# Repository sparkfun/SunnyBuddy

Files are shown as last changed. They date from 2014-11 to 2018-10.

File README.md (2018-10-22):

Sunny Buddy - MPPT Solar Charger
================================

Sunny Buddy

[*Sunny Buddy (PRT-12885)*](https://www.sparkfun.com/products/12885)

This is a maximum power point tracking solar charger for single-cell LiPo batteries. 

Repository Contents
-------------------
* **/Fritzing** - Fritzing Example wiring images
* **/Hardware** - All Eagle design files (.brd, .sch)
* **/Production** - Test bed files and production panel files

Documentation
--------------
* **[Hookup Guide](https://learn.sparkfun.com/tutorials/sunny-buddy-solar-charger-v13-hookup-guide)** - Basic hookup guide for the Sunny Buddy.

Product Versions
----------------
* [PRT-12885 ](https://www.sparkfun.com/products/12885 )- Version 1.3
* [PRT-12084](https://www.sparkfun.com/products/12084) - Version 1.0

Version History
---------------
* [v10](https://github.com/sparkfun/SunnyBuddy/tree/HW_V1.0) -GitHub files for v1.0

License Information
-------------------
The hardware is released under [Creative Commons ShareAlike 4.0 International](https://creativecommons.org/licenses/by-sa/4.0/).
The code is beerware; if you see me (or any other SparkFun employee) at the local, and you've found our code helpful, please buy us a round!

Distributed as-is; no warranty is given.

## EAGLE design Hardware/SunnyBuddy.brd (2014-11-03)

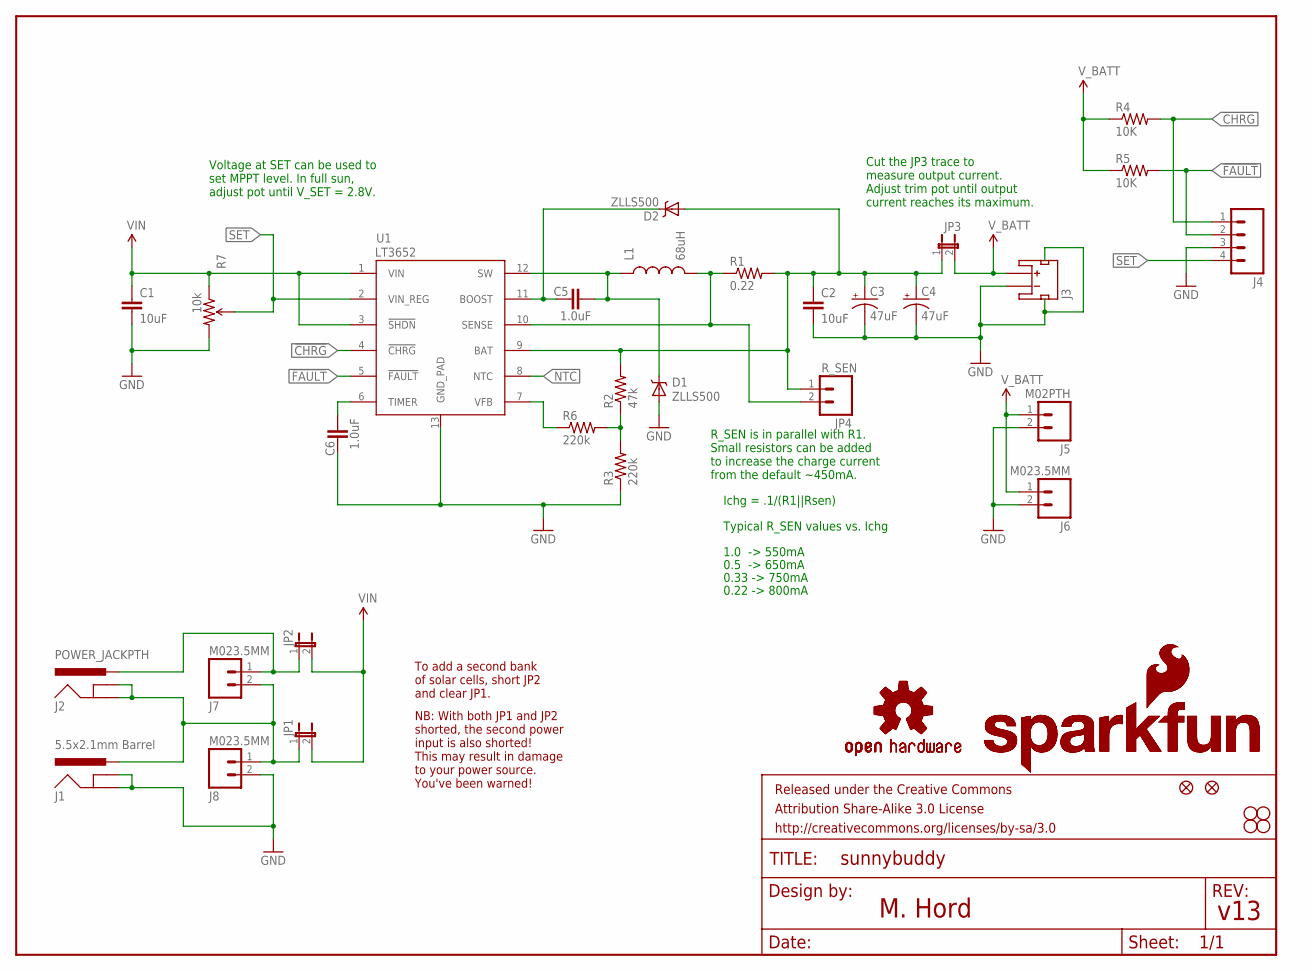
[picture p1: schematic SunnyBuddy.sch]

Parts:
C1: 10uF; 1210
C2: 10uF; 1206
C3, C4: 47uF; EIA3528
C5, C6: 1.0uF; 0603-CAP
D1, D2: ZLLS500; SOT23
FID1, FID2: FIDUCIAL1X2; FIDUCIAL-1X2
FRAME1: FRAME-LETTER; CREATIVE_COMMONS
J1: 5.5x2.1mm Barrel; POWER_JACK_SMD
J2: POWER_JACKPTH; POWER_JACK_PTH
J3: JST_2MM_MALE; JST-2-SMD
J4: M04PTH; 1X04
J5: M02PTH; 1X02
J6, J7, J8: M023.5MM; SCREWTERMINAL-3.5MM-2
JP1: JUMPER-2SMD-NC; SJ_2S
JP2: JUMPER-2SMD-NO; SJ_2S-NO
JP3: JUMPER-PTH-2-NC; PTH-JUMPER-NC_BOTTOM_NO_SILK
JP4: R_SEN; 1X02
L1: 68uH; CR75
LOGO1: SFE_LOGO_NAME_FLAME.2_INCH; SFE_LOGO_NAME_FLAME_.2
LOGO2: OSHW-LOGOM; OSHW-LOGO-M
LOGO3: OSHW-LOGOS; OSHW-LOGO-S
LOGO4: SFE_LOGO_NAME_FLAME.3_INCH; SFE_LOGO_NAME_FLAME_.3
R1: 0.22; 0805
R2: 47k; 0603-RES
R3, R6: 220k; 0603-RES
R4, R5: 10K; 0603-RES
R7: 10k; TRIMPOT-3MM
STANDOFF1, STANDOFF2, STANDOFF3, STANDOFF4: STAND-OFF
U1: LT3652; MSOP-12_GND

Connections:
!CHRG: J4.1, R4.2, U1.4 (!CHRG)
!FAULT: J4.2, R5.2, U1.5 (!FAULT)
BOOST: C5.1, D2.3 (C), U1.11 (BOOST)
FB: R2.1, R3.2, R6.2
GND: C1.2, C2.2, C3.C (-), C4.C (-), C6.1, D1.1 (A), J1.GND (GNDBREAK), J1.P$4 (GND), J3.1 (-), J3.NC1 (PAD1), J3.NC2 (PAD2), J4.3, J5.2, J6.2, J8.2, R3.1, R7.3 (CW), U1.13 (GND_PAD)
unnamed: R6.1, U1.7 (VFB)
unnamed: C2.1, C3.A (+), C4.A (+), D2.1 (A), JP3.1, JP4.1, R1.2, R2.2, U1.9 (BAT)
unnamed: J1.VIN0 (PWR), J2.GND, J2.GNDBREAK, J7.2, J8.1, JP1.1
NTC: U1.8 (NTC)
SENSE: JP4.2, L1.P$2 (2), R1.1, U1.10 (SENSE)
SET: J4.4, R7.2 (WIPER), U1.2 (VIN_REG)
SFSASDF: J2.PWR, J7.1, JP2.1
SW: C5.2, D1.3 (C), L1.P$1 (1), U1.12 (SW)
TIMER: C6.2, U1.6 (TIMER)
VIN: C1.1, JP1.2, JP2.2, R7.1 (CCW), U1.1 (VIN), U1.3 (!SHDN)
V_BATT: J3.2 (+), J5.1, J6.1, JP3.2, R4.1, R5.1

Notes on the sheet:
To add a second bank of solar cells, short JP2 and clear JP1.
NB: With both JP1 and JP2 shorted, the second power input is also shorted! This may result in damage to your power source. You've been warned!
v13
M. Hord
Cut the JP3 trace to measure output current. Adjust trim pot until output current reaches its maximum.
R_SEN is in parallel with R1. Small resistors can be added to increase the charge current from the default ~450mA.
0.22 -> 800mA
Ichg = .1/(R1||Rsen)
Typical R_SEN values vs. Ichg
1.0 -> 550mA
0.33 -> 750mA
0.5 -> 650mA
Voltage at SET can be used to set MPPT level. In full sun, adjust pot until V_SET = 2.8V.

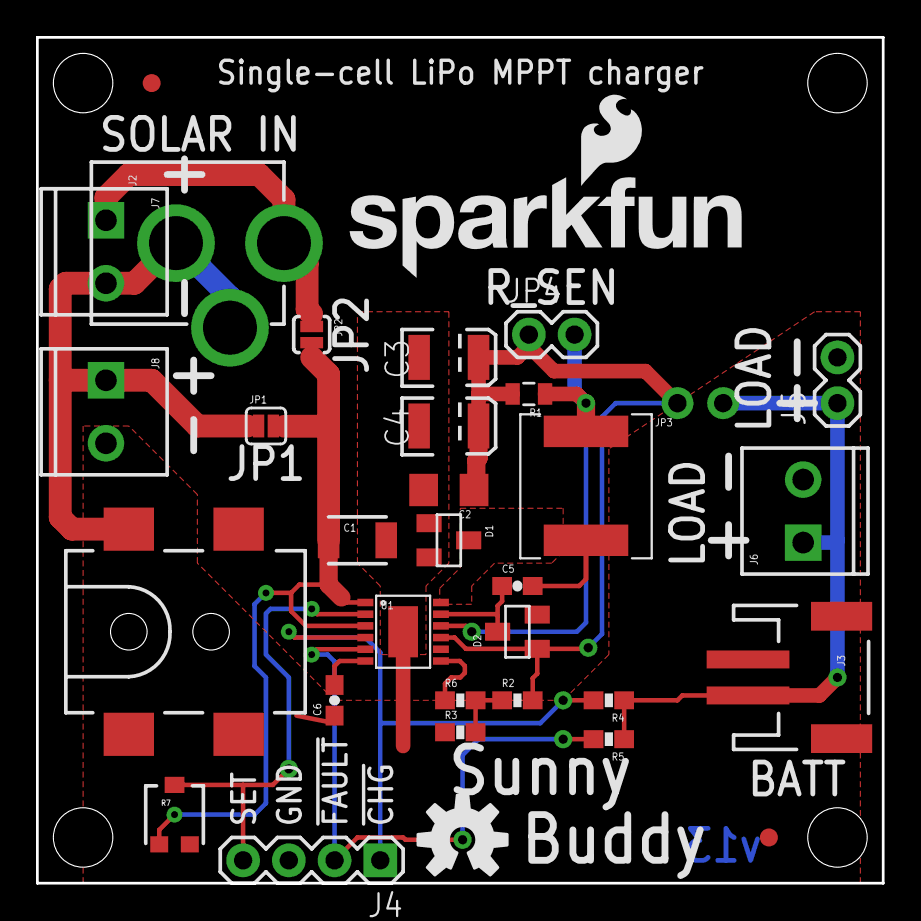
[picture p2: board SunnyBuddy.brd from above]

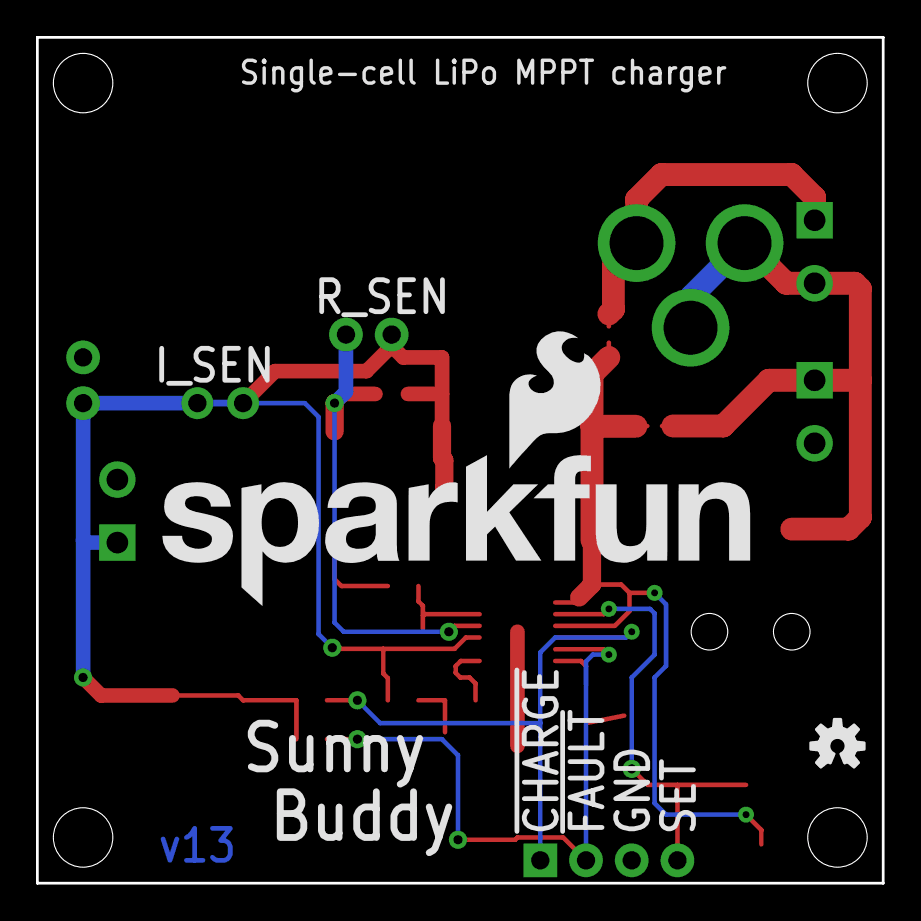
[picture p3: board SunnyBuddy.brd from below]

Board: 2 copper layers, 47.0 x 47.0 mm, 40 parts (2 on the bottom side), 15 nets.

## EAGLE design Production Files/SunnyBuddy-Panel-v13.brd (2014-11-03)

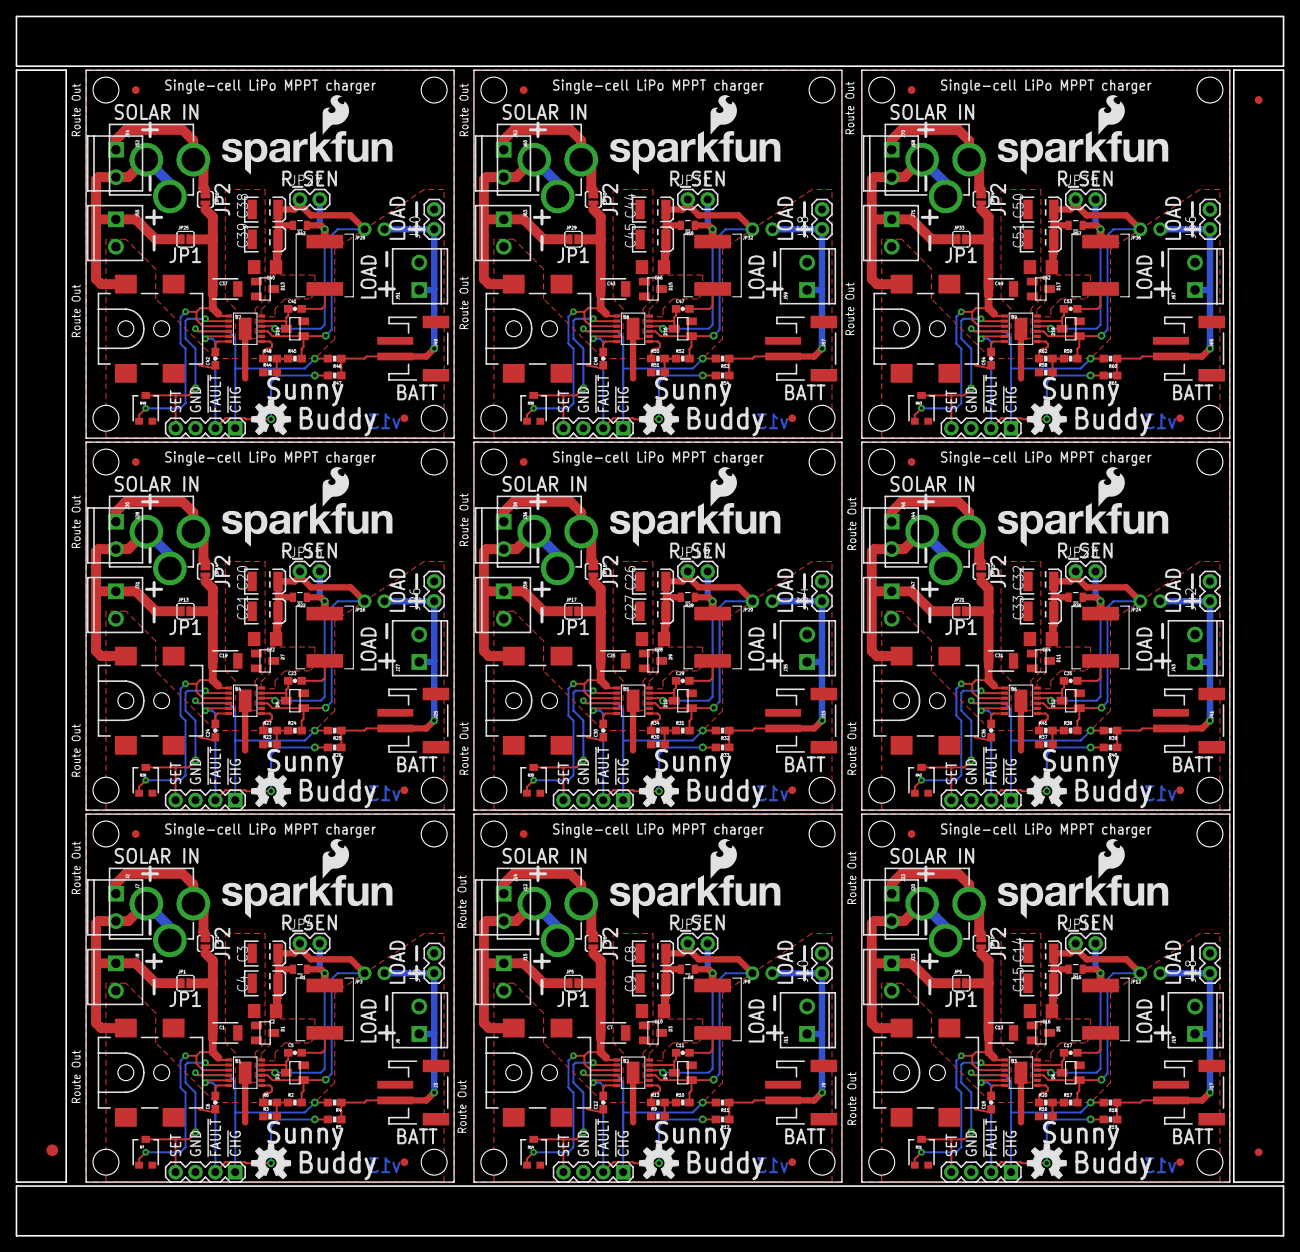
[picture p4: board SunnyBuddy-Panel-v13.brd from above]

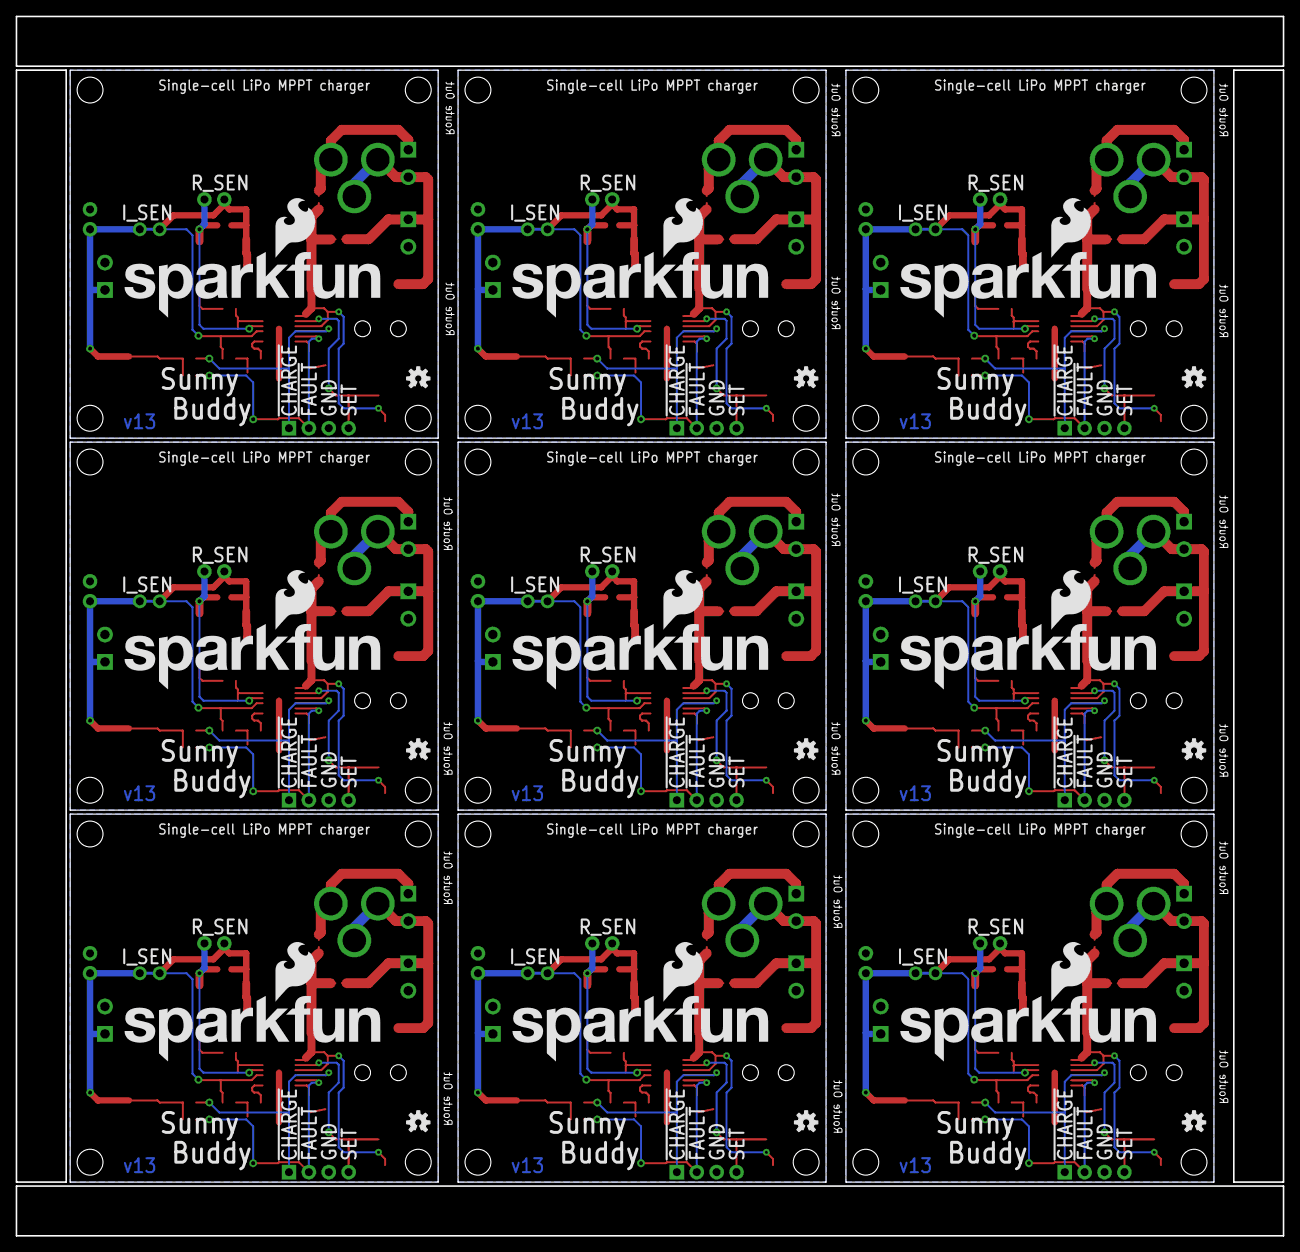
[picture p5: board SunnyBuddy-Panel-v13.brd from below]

Board: 2 copper layers, 161.8 x 155.7 mm, 354 parts (18 on the bottom side), 135 nets.

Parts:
C1, C7, C13, C19, C25, C31, C37, C43, C49: 10uF; 1210
C2, C10, C16, C22, C28, C34, C40, C46, C52: 10uF; 1206
C3, C4, C8, C9, C14, C15, C20, C21, C26, C27, C32, C33, C38, C39, C44, C45, C50, C51: 47uF; EIA3528
C5, C6, C11, C12, C17, C18, C23, C24, C29, C30, C35, C36, C41, C42, C47, C48, C53, C54: 1.0uF; 0603-CAP
D1, D2, D3, D4, D5, D6, D7, D8, D9, D10, D11, D12, D13, D14, D15, D16, D17, D18: ZLLS500; SOT23
E$1: FIDUCIAL-1.5X3
E$4, E$6: FIDUCIAL-1X2
FID1, FID2, FID3, FID4, FID5, FID6, FID7, FID8, FID9, FID10, FID11, FID12, FID13, FID14, FID15, FID16, FID17, FID18: FIDUCIAL1X2; FIDUCIAL-1X2
J1, J13, J21, J29, J37, J45, J53, J61, J69: 5.5x2.1mm Barrel; POWER_JACK_SMD
J2, J14, J22, J30, J38, J46, J54, J62, J70: POWER_JACKPTH; POWER_JACK_PTH
J3, J9, J17, J25, J33, J41, J49, J57, J65: JST-2-SMD
J4, J16, J24, J32, J40, J48, J56, J64, J72: 1X04
J5, J10, J18, J26, J34, J42, J50, J58, J66: M02PTH; 1X02
J6, J7, J8, J11, J12, J15, J19, J20, J23, J27, J28, J31, J35, J36, J39, J43, J44, J47, J51, J52, J55, J59, J60, J63, J67, J68, J71: M023.5MM; SCREWTERMINAL-3.5MM-2
JP1, JP5, JP9, JP13, JP17, JP21, JP25, JP29, JP33: SJ_2S
JP2, JP6, JP10, JP14, JP18, JP22, JP26, JP30, JP34: SJ_2S-NO
JP3, JP8, JP12, JP16, JP20, JP24, JP28, JP32, JP36: JUMPER-PTH-2-NC; PTH-JUMPER-NC_BOTTOM_NO_SILK
JP4, JP7, JP11, JP15, JP19, JP23, JP27, JP31, JP35: R_SEN; 1X02
L1, L2, L3, L4, L5, L6, L7, L8, L9: 68uH; CR75
LOGO1, LOGO5, LOGO9, LOGO13, LOGO17, LOGO21, LOGO25, LOGO29, LOGO33: SFE_LOGO_NAME_FLAME.2_INCH; SFE_LOGO_NAME_FLAME_.2
LOGO2, LOGO6, LOGO10, LOGO14, LOGO18, LOGO22, LOGO26, LOGO30, LOGO34: OSHW-LOGOM; OSHW-LOGO-M
LOGO3, LOGO7, LOGO11, LOGO15, LOGO19, LOGO23, LOGO27, LOGO31, LOGO35: OSHW-LOGOS; OSHW-LOGO-S
LOGO4, LOGO8, LOGO12, LOGO16, LOGO20, LOGO24, LOGO28, LOGO32, LOGO36: SFE_LOGO_NAME_FLAME.3_INCH; SFE_LOGO_NAME_FLAME_.3
R1, R8, R15, R22, R29, R36, R43, R50, R57: 0.22; 0805
R2, R10, R17, R24, R31, R38, R45, R52, R59: 47k; 0603-RES
R3, R6, R9, R13, R16, R20, R23, R27, R30, R34, R37, R41, R44, R48, R51, R55, R58, R62: 220k; 0603-RES
R4, R5, R11, R12, R18, R19, R25, R26, R32, R33, R39, R40, R46, R47, R53, R54, R60, R61: 10K; 0603-RES
R7, R14, R21, R28, R35, R42, R49, R56, R63: 10k; TRIMPOT-3MM
STANDOFF1, STANDOFF2, STANDOFF3, STANDOFF4, STANDOFF5, STANDOFF6, STANDOFF7, STANDOFF8, STANDOFF9, STANDOFF10, STANDOFF11, STANDOFF12, STANDOFF13, STANDOFF14, STANDOFF15, STANDOFF16, STANDOFF17, STANDOFF18, STANDOFF19, STANDOFF20, STANDOFF21, STANDOFF22, STANDOFF23, STANDOFF24, STANDOFF25, STANDOFF26, STANDOFF27, STANDOFF28, STANDOFF29, STANDOFF30, STANDOFF31, STANDOFF32, STANDOFF33, STANDOFF34, STANDOFF35, STANDOFF36: STAND-OFF
U1, U2, U3, U4, U5, U6, U7, U8, U9: LT3652; MSOP-12_GND

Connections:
!CHRG: J4.1, R4.2, U1.4
!CHRG1: J16.1, R11.2, U2.4
!CHRG2: J24.1, R18.2, U3.4
!CHRG3: J32.1, R25.2, U4.4
!CHRG4: J40.1, R32.2, U5.4
!CHRG5: J48.1, R39.2, U6.4
!CHRG6: J56.1, R46.2, U7.4
!CHRG7: J64.1, R53.2, U8.4
!CHRG8: J72.1, R60.2, U9.4
!FAULT: J4.2, R5.2, U1.5
!FAULT1: J16.2, R12.2, U2.5
!FAULT2: J24.2, R19.2, U3.5
!FAULT3: J32.2, R26.2, U4.5
!FAULT4: J40.2, R33.2, U5.5
!FAULT5: J48.2, R40.2, U6.5
!FAULT6: J56.2, R47.2, U7.5
!FAULT7: J64.2, R54.2, U8.5
!FAULT8: J72.2, R61.2, U9.5
BOOST: C5.1, D2.3, U1.11
BOOST1: C11.1, D4.3, U2.11
BOOST2: C17.1, D6.3, U3.11
BOOST3: C23.1, D8.3, U4.11
BOOST4: C29.1, D10.3, U5.11
BOOST5: C35.1, D12.3, U6.11
BOOST6: C41.1, D14.3, U7.11
BOOST7: C47.1, D16.3, U8.11
BOOST8: C53.1, D18.3, U9.11
FB: R2.1, R3.2, R6.2
FB1: R9.2, R10.1, R13.2
FB2: R16.2, R17.1, R20.2
FB3: R23.2, R24.1, R27.2
FB4: R30.2, R31.1, R34.2
FB5: R37.2, R38.1, R41.2
FB6: R44.2, R45.1, R48.2
FB7: R51.2, R52.1, R55.2
FB8: R58.2, R59.1, R62.2
GND: C1.2, C2.2, C3.C, C4.C, C6.1, D1.1, J1.GND, J1.P$4, J3.1, J3.NC1, J3.NC2, J4.3, J5.2, J6.2, J8.2, R3.1, R7.3, U1.13
GND1: C7.2, C8.C, C9.C, C10.2, C12.1, D3.1, J9.1, J9.NC1, J9.NC2, J10.2, J11.2, J13.GND, J13.P$4, J15.2, J16.3, R9.1, R14.3, U2.13
GND2: C13.2, C14.C, C15.C, C16.2, C18.1, D5.1, J17.1, J17.NC1, J17.NC2, J18.2, J19.2, J21.GND, J21.P$4, J23.2, J24.3, R16.1, R21.3, U3.13
GND3: C19.2, C20.C, C21.C, C22.2, C24.1, D7.1, J25.1, J25.NC1, J25.NC2, J26.2, J27.2, J29.GND, J29.P$4, J31.2, J32.3, R23.1, R28.3, U4.13
GND4: C25.2, C26.C, C27.C, C28.2, C30.1, D9.1, J33.1, J33.NC1, J33.NC2, J34.2, J35.2, J37.GND, J37.P$4, J39.2, J40.3, R30.1, R35.3, U5.13
GND5: C31.2, C32.C, C33.C, C34.2, C36.1, D11.1, J41.1, J41.NC1, J41.NC2, J42.2, J43.2, J45.GND, J45.P$4, J47.2, J48.3, R37.1, R42.3, U6.13
GND6: C37.2, C38.C, C39.C, C40.2, C42.1, D13.1, J49.1, J49.NC1, J49.NC2, J50.2, J51.2, J53.GND, J53.P$4, J55.2, J56.3, R44.1, R49.3, U7.13
GND7: C43.2, C44.C, C45.C, C46.2, C48.1, D15.1, J57.1, J57.NC1, J57.NC2, J58.2, J59.2, J61.GND, J61.P$4, J63.2, J64.3, R51.1, R56.3, U8.13
GND8: C49.2, C50.C, C51.C, C52.2, C54.1, D17.1, J65.1, J65.NC1, J65.NC2, J66.2, J67.2, J69.GND, J69.P$4, J71.2, J72.3, R58.1, R63.3, U9.13
unnamed: R6.1, U1.7
unnamed: C2.1, C3.A, C4.A, D2.1, JP3.1, JP4.1, R1.2, R2.2, U1.9
unnamed: J12.2, J13.VIN0, J14.GND, J14.GNDBREAK, J15.1, JP5.1
unnamed: J1.VIN0, J2.GND, J2.GNDBREAK, J7.2, J8.1, JP1.1
unnamed: R13.1, U2.7
unnamed: C8.A, C9.A, C10.1, D4.1, JP7.1, JP8.1, R8.2, R10.2, U2.9
unnamed: J20.2, J21.VIN0, J22.GND, J22.GNDBREAK, J23.1, JP9.1
unnamed: R20.1, U3.7
unnamed: C14.A, C15.A, C16.1, D6.1, JP11.1, JP12.1, R15.2, R17.2, U3.9
unnamed: J28.2, J29.VIN0, J30.GND, J30.GNDBREAK, J31.1, JP13.1
unnamed: R27.1, U4.7
unnamed: C20.A, C21.A, C22.1, D8.1, JP15.1, JP16.1, R22.2, R24.2, U4.9
unnamed: J36.2, J37.VIN0, J38.GND, J38.GNDBREAK, J39.1, JP17.1
unnamed: R34.1, U5.7
unnamed: C26.A, C27.A, C28.1, D10.1, JP19.1, JP20.1, R29.2, R31.2, U5.9
unnamed: J44.2, J45.VIN0, J46.GND, J46.GNDBREAK, J47.1, JP21.1
unnamed: R41.1, U6.7
unnamed: C32.A, C33.A, C34.1, D12.1, JP23.1, JP24.1, R36.2, R38.2, U6.9
unnamed: J52.2, J53.VIN0, J54.GND, J54.GNDBREAK, J55.1, JP25.1
unnamed: R48.1, U7.7
unnamed: C38.A, C39.A, C40.1, D14.1, JP27.1, JP28.1, R43.2, R45.2, U7.9
unnamed: J60.2, J61.VIN0, J62.GND, J62.GNDBREAK, J63.1, JP29.1
unnamed: R55.1, U8.7
unnamed: C44.A, C45.A, C46.1, D16.1, JP31.1, JP32.1, R50.2, R52.2, U8.9
unnamed: J68.2, J69.VIN0, J70.GND, J70.GNDBREAK, J71.1, JP33.1
unnamed: R62.1, U9.7
unnamed: C50.A, C51.A, C52.1, D18.1, JP35.1, JP36.1, R57.2, R59.2, U9.9
SENSE: JP4.2, L1.P$2, R1.1, U1.10
SENSE1: JP7.2, L2.P$2, R8.1, U2.10
SENSE2: JP11.2, L3.P$2, R15.1, U3.10
SENSE3: JP15.2, L4.P$2, R22.1, U4.10
SENSE4: JP19.2, L5.P$2, R29.1, U5.10
SENSE5: JP23.2, L6.P$2, R36.1, U6.10
SENSE6: JP27.2, L7.P$2, R43.1, U7.10
SENSE7: JP31.2, L8.P$2, R50.1, U8.10
SENSE8: JP35.2, L9.P$2, R57.1, U9.10
SET: J4.4, R7.2, U1.2
SET1: J16.4, R14.2, U2.2
SET2: J24.4, R21.2, U3.2
SET3: J32.4, R28.2, U4.2
SET4: J40.4, R35.2, U5.2
SET5: J48.4, R42.2, U6.2
SET6: J56.4, R49.2, U7.2
SET7: J64.4, R56.2, U8.2
SET8: J72.4, R63.2, U9.2
SFSASDF: J2.PWR, J7.1, JP2.1
SFSASDF1: J12.1, J14.PWR, JP6.1
SFSASDF2: J20.1, J22.PWR, JP10.1
SFSASDF3: J28.1, J30.PWR, JP14.1
SFSASDF4: J36.1, J38.PWR, JP18.1
SFSASDF5: J44.1, J46.PWR, JP22.1
SFSASDF6: J52.1, J54.PWR, JP26.1
SFSASDF7: J60.1, J62.PWR, JP30.1
SFSASDF8: J68.1, J70.PWR, JP34.1
SW: C5.2, D1.3, L1.P$1, U1.12
SW1: C11.2, D3.3, L2.P$1, U2.12
SW2: C17.2, D5.3, L3.P$1, U3.12
SW3: C23.2, D7.3, L4.P$1, U4.12
SW4: C29.2, D9.3, L5.P$1, U5.12
SW5: C35.2, D11.3, L6.P$1, U6.12
SW6: C41.2, D13.3, L7.P$1, U7.12
SW7: C47.2, D15.3, L8.P$1, U8.12
SW8: C53.2, D17.3, L9.P$1, U9.12
TIMER: C6.2, U1.6
TIMER1: C12.2, U2.6
TIMER2: C18.2, U3.6
TIMER3: C24.2, U4.6
TIMER4: C30.2, U5.6
TIMER5: C36.2, U6.6
TIMER6: C42.2, U7.6
TIMER7: C48.2, U8.6
TIMER8: C54.2, U9.6
VIN: C1.1, JP1.2, JP2.2, R7.1, U1.1, U1.3
VIN1: C7.1, JP5.2, JP6.2, R14.1, U2.1, U2.3
VIN2: C13.1, JP9.2, JP10.2, R21.1, U3.1, U3.3
VIN3: C19.1, JP13.2, JP14.2, R28.1, U4.1, U4.3
VIN4: C25.1, JP17.2, JP18.2, R35.1, U5.1, U5.3
VIN5: C31.1, JP21.2, JP22.2, R42.1, U6.1, U6.3
VIN6: C37.1, JP25.2, JP26.2, R49.1, U7.1, U7.3
VIN7: C43.1, JP29.2, JP30.2, R56.1, U8.1, U8.3
VIN8: C49.1, JP33.2, JP34.2, R63.1, U9.1, U9.3
V_BATT: J3.2, J5.1, J6.1, JP3.2, R4.1, R5.1
V_BATT1: J9.2, J10.1, J11.1, JP8.2, R11.1, R12.1
V_BATT2: J17.2, J18.1, J19.1, JP12.2, R18.1, R19.1
V_BATT3: J25.2, J26.1, J27.1, JP16.2, R25.1, R26.1
V_BATT4: J33.2, J34.1, J35.1, JP20.2, R32.1, R33.1
V_BATT5: J41.2, J42.1, J43.1, JP24.2, R39.1, R40.1
V_BATT6: J49.2, J50.1, J51.1, JP28.2, R46.1, R47.1
V_BATT7: J57.2, J58.1, J59.1, JP32.2, R53.1, R54.1
V_BATT8: J65.2, J66.1, J67.1, JP36.2, R60.1, R61.1

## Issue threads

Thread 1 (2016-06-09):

Breakout NTC pin for cold weather charging

nseidle, 2016-06-09:
From customer discussion on [weather station tutorial](https://learn.sparkfun.com/tutorials/weather-station-wirelessly-connected-to-wunderground/discuss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).

ToniCorinne, 2016-06-13:
FoTR has been pinged regarding this in Sparkle.

Closed 2016-07-19.

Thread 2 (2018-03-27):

Fritzing Files have not been updated.

dave373, 2018-03-27:
I was trying to re-configure this board for a 12V SLA and went looking for the layouts so I know which resistor is which. On the readme file, you have the current board, but the Fritzing files haven't been updated. Could someone please do this?  Thanks.

loricrotser, 2018-08-16:
Apologies for the long reply time - I am just now getting to this!

Fritzing has been updated for v1.3. Please let us know if you need anything else!

[https://github.com/sparkfun/Fritzing_Parts/blob/master/products/12885_sfe_sunny_buddy_solar_power_v13.fzpz](https://github.com/sparkfun/Fritzing_Parts/blob/master/products/12885_sfe_sunny_buddy_solar_power_v13.fzpz)

Closed 2018-08-16.

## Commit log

2013-08-14 Proto commit
    [SunnyBuddy.brd, SunnyBuddy.sch]
2013-12-04 New inductor, better fb, add CHG and FLT
    [SunnyBuddy.brd, SunnyBuddy.sch]
2013-12-04 Change version numbers
    [SunnyBuddy.brd, SunnyBuddy.sch]
2014-01-08 Release to reds, chg v#, move 1 via, add pol silk
    [SunnyBuddy.brd, SunnyBuddy.sch]
2014-01-21 Added local board fiducials
    [SunnyBuddy.brd, SunnyBuddy.sch]
2014-01-21 created panel
    [SunnyBuddy-Panel-v10.brd]
2014-04-25 Add trimpot, adjust output res values
    [SunnyBuddy.brd, SunnyBuddy.sch]
2014-05-07 Change 10th vias to 15th
    [SunnyBuddy.brd]
2014-05-22 Add current sense jumper, set V node, Fritzing
    [SunnyBuddy.brd, SunnyBuddy.sch]
2014-06-24 Changes to silk, only, for production
    [SunnyBuddy.brd, SunnyBuddy.sch]
2014-06-26 added board fiducials
    [SunnyBuddy.brd, SunnyBuddy.sch]
2014-06-26 created panel v13
    [SunnyBuddy-Panel-v13.brd]
2014-06-26 added route out instructions to panel
    [SunnyBuddy-Panel-v13.brd]
2014-11-03 Fixing brd file merge conflicts
    [SunnyBuddy-Panel-v10.brd, SunnyBuddy.brd, SunnyBuddy.sch]

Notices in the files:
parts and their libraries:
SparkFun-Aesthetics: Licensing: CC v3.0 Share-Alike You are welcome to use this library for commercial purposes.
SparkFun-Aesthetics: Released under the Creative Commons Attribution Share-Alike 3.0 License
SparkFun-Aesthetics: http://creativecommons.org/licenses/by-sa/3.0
